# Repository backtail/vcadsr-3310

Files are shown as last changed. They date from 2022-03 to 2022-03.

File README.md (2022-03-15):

# vcadsr 3310
8HP Eurorack module

Voltage Contralled Envelope Generator

### Render
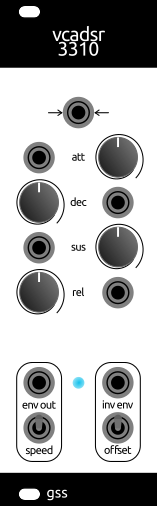
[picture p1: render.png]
 

### Pots
Rregular ADSR behaviour

### Jacks
- **arrows**: gate input  
- **env out**: regular envelope
- **inv env**: inverse envelope

### Switches
- **speed**: `up` = fast, `down` = slow
- **offset**: `up` = inv env between -5V and 0V, `down` = inv env between 0V and 5V

## Footprints Libraries
Use provided submodule folder to link footprints locally in the project
- OS_Connectors
- OS_Scribbles

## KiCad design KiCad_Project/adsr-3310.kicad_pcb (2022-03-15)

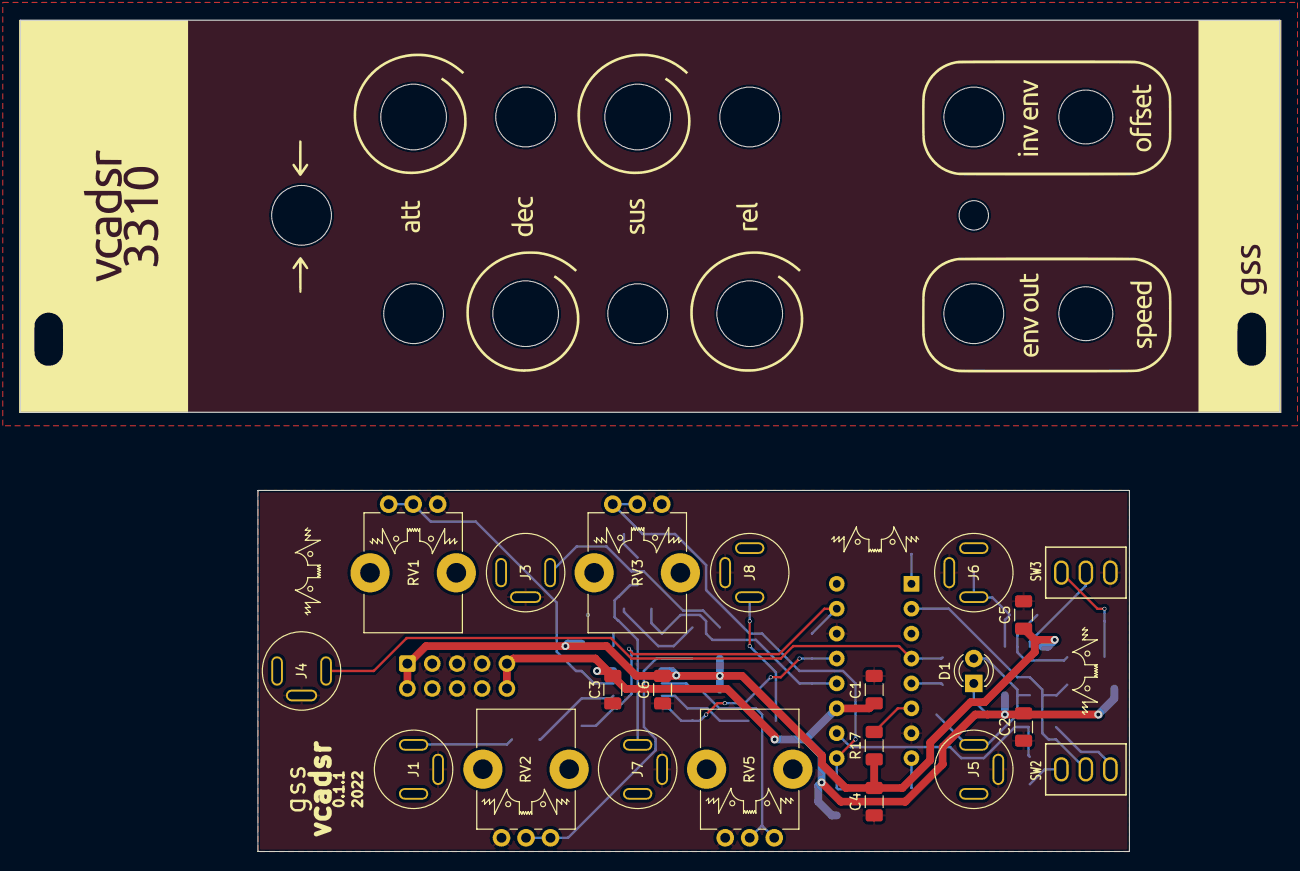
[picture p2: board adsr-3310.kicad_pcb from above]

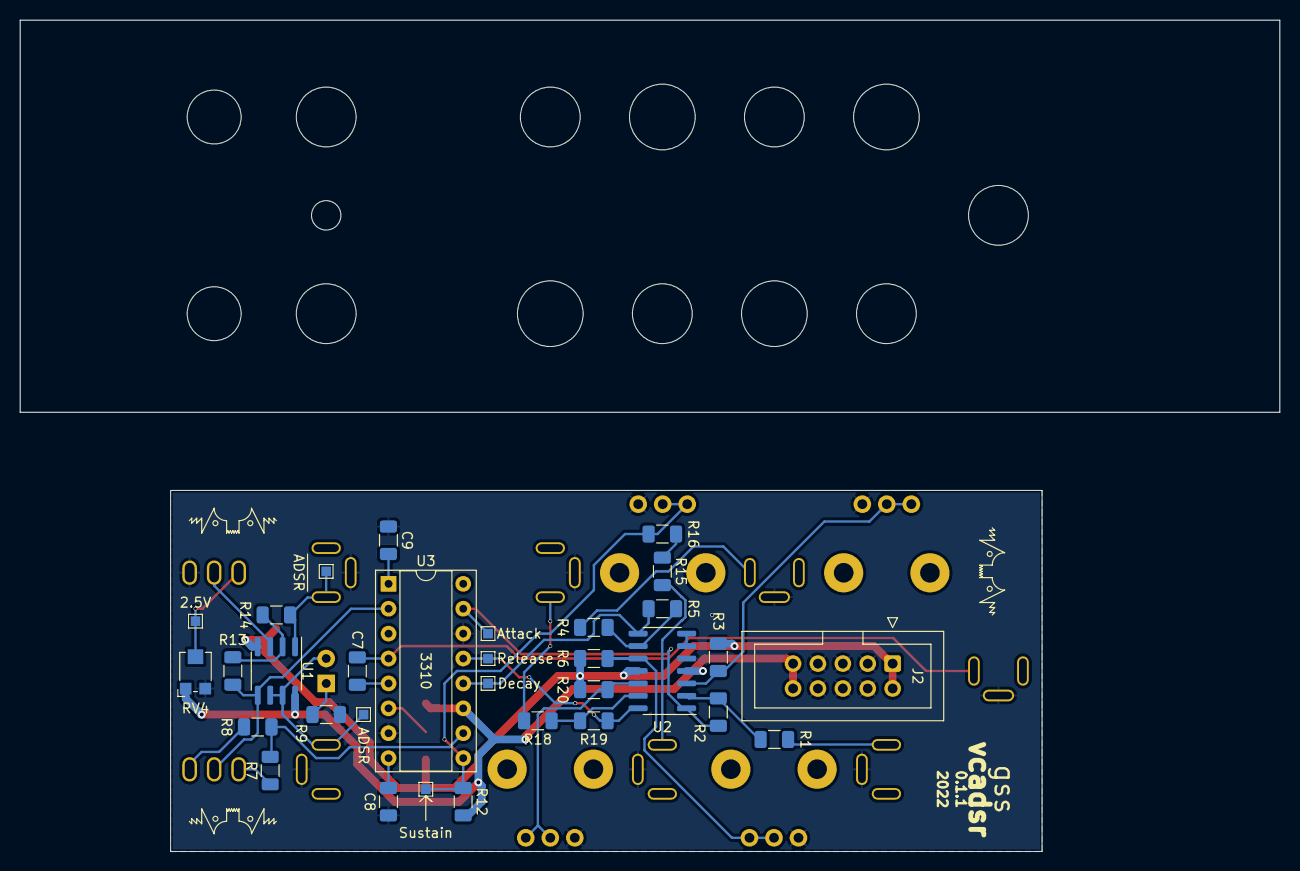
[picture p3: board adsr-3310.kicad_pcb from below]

Board: 2 copper layers, 88.9 x 36.8 mm, 63 parts (35 on the bottom side), 34 nets.

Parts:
2.5V: 2.5V; TestPoint_Pad_1.0x1.0mm
  : alien_small
  #2,   #3,   #4,   #5,   #6,   #7,   #8,   #9,   #10: alien_small
ADSR: ADSR; TestPoint_Pad_1.0x1.0mm
ADSR#2: inv. ADSR; TestPoint_Pad_1.0x1.0mm
Attack: [0V,-240mV]; TestPoint_Pad_1.0x1.0mm
C1, C2, C3, C4, C5, C6: 100nF; C_1206_3216Metric
C7: 3nF; C_1206_3216Metric
C8: 68nF; C_1206_3216Metric
C9: 39nF; C_1206_3216Metric
D1: Blue; LED_D3.0mm
Decay: [0V,-240mV]; TestPoint_Pad_1.0x1.0mm
J1: CV Attack; PJ-392
J2: Power; IDC-Header_2x05_P2.54mm_Vertical
J3: CV Decay; PJ-392
J4: CV Gate; PJ-392
J5: Envelope; PJ-392
J6: Inverse Env; PJ-392
J7: CV Sustain; PJ-392
J8: CV Release; PJ-392
R1, R4, R13, R14, R18: 100k; R_1206_3216Metric
R2, R5, R19: 4k7; R_1206_3216Metric
R3, R6, R20: 470k; R_1206_3216Metric
R7: 20k; R_1206_3216Metric
R8: 30k; R_1206_3216Metric
R9: 10k; R_1206_3216Metric
R12: 140k; R_1206_3216Metric
R15: 56k; R_1206_3216Metric
R16: 2k7; R_1206_3216Metric
R17: 470; R_1206_3216Metric
RV1, RV2, RV5: 10k log; Potentiometer_Alps_RK09K_Single_Vertical
RV3: 100k lin; Potentiometer_Alps_RK09K_Single_Vertical
RV4: 100k; Potentiometer_Bourns_TC33X_Vertical
Release: [0V,-240mV]; TestPoint_Pad_1.0x1.0mm
SW2, SW3: SW_SPDT; STMS-102-Micro_Toggle_Switch_SPDT
Sustain: [0V,5V]; TestPoint_Pad_1.0x1.0mm
U1: LM358; SOIC-8_3.9x4.9mm_P1.27mm
U2: TL074; SOIC-14_3.9x8.7mm_P1.27mm
U3: AS3310; DIP-16_W7.62mm_Socket

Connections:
+12V: C1.2, C2.2, C3.2, J2.9, J2.10, R12.2, RV4.1, U1.8 (V+), U2.4 (V+), U3.11 (VCC)
-12V: C4.1, C5.1, C6.1, J2.1, J2.2, R3.2, R6.2, R17.1, R20.2, U1.4 (V-), U2.11 (V-)
Attack: Attack.1, R2.1, U2.1, U3.15 (VCA)
Decay: Decay.1, R5.1, U2.8, U3.12 (VCD)
GND: C1.1, C2.1, C3.1, C4.2, C5.2, C6.2, C8.1, C9.2, J1.S, J2.3, J2.4, J2.5, J2.6, J2.7, J2.8, J3.S, J4.S, J5.S, J6.S, J7.S, J8.S, R9.1, RV1.3, RV2.3, RV3.3, RV4.3, RV5.3, SW3.3 (C), U2.5 (+), U3.7 (PGND), U3.14 (GND)
unnamed: C7.1, U3.5 (TRIG)
unnamed: C7.2, J4.T, U3.4 (GATE)
unnamed: C8.2, U3.8 (CCOMP)
unnamed: C9.1, U3.1 (CAP)
unnamed: D1.1 (K), R9.2
unnamed: ADSR.1, D1.2 (A), J5.T, U1.6 (-), U1.7
unnamed: J1.T, R1.2
unnamed: J3.T, R4.2
unnamed: ADSR#2.1, J6.T, R14.1, U1.1
unnamed: J7.T, R15.2
unnamed: J8.T, R18.2
unnamed: R1.1, R2.2, U2.2 (-)
unnamed: R3.1, RV1.1, RV1.2, U2.3 (+)
unnamed: R4.1, R5.2, U2.9 (-)
unnamed: R6.1, RV2.1, RV2.2, U2.10 (+)
unnamed: R7.1, SW2.1 (A)
unnamed: R7.2, R8.1, U3.10 (IIN)
unnamed: R8.2, SW2.3 (C)
unnamed: R13.1, R14.2, U1.2 (-)
unnamed: R13.2, SW2.2 (B), U1.5 (+), U3.2 (ENVOUT)
unnamed: R15.1, R16.2
unnamed: R17.2, U3.6 (VEE)
unnamed: R18.1, R19.2, U2.13 (-)
unnamed: R20.1, RV5.1, RV5.2, U2.12 (+)
unnamed: 2.5V.1, RV4.2, SW3.1 (A)
unnamed: SW3.2 (B), U1.3 (+)
unnamed: U2.6 (-), U2.7
Release: R19.1, Release.1, U2.14, U3.13 (VCR)
Sustain: R12.1, R16.1, RV3.1, RV3.2, Sustain.1, U3.9 (VCS)

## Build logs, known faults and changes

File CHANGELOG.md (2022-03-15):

# VCADSR based on the 3310 

# 0.1.1 
    * ADSR pots were connected to wrong way around
    * changed R7 to 100k (speed of EG curve)
    * changed R9 to 10k (current limit for LED)
    * changed RV4 to 3x3mm trim pot footprint
    + added year and revision
# 0.1.0
    + first version

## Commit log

2022-03-15 inital commit
    [adsr-3310.kicad_pcb, adsr-3310.kicad_sch]
2022-03-15 add footprints submodule
2022-03-15 add BOM
